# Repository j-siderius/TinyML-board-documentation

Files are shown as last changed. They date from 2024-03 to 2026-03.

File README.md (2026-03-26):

# TinyML Board Documentation

Board version: 2.1

The TinyML board is a development board specifically tailored to the exploration of TinyML concepts and to test possible applications of TinyML in an easy way. It features a powerfull microcontroller as well as a suite of sensors to sense the environment. Combined with a special TensorFlow Lite Micro library, it is easy to use this devide and start deploying machine learning models to the Edge.

<div align="center">
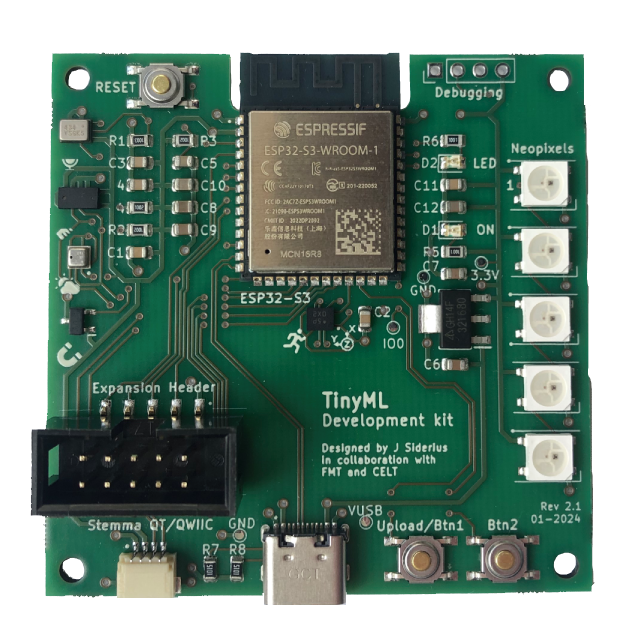
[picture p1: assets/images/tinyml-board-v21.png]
TinyML board
    
</div>

## Contents
- [Quick start](#quick-start)
- [Hardware](#hardware)
  - [Sensors](#sensors)
  - [Processor](#processor)
  - [Input/Output](#inputoutput)
  - [Expansion headers](#expansion-headers)
- [Software](#software)
  - [Arduino](#arduino-ide)
  - [IDE configuration](#ide-configuration)
  - [Serial Port Setup](#serial-port-setup)
  - [Libraries](#arduino-libraries)
  - [TensorFlow Lite Micro library](#tensorflow-lite-micro-library)
  - [Uploading code](#uploading-code)
- [Code examples](#code-examples)
  - [Sensor examples](#sensor-examples)
  - [I/O examples](#io-examples)
  - [TensorFlow Lite Micro examples](#tensorflow-lite-micro-examples)
  - [Board tests](#board-tests)
- [Frequently Encountered Issues](#frequently-encountered-issues)
- [License](#license-and-contact)

## Quick start

 1. Install the ESP32 board support into Arduino IDE by adding the Espressif repository to the Board Manager and then downloading the ESP32 boards - [Espressif Arduino ESP32 installation](https://docs.espressif.com/projects/arduino-esp32/en/latest/installing.html#installing-using-arduino-ide).
 2. Install libraries for the sensors ([Sparkfun BME280](https://github.com/sparkfun/SparkFun_BME280_Arduino_Library), [Sparkfun BMI270](https://github.com/sparkfun/SparkFun_BMI270_Arduino_Library), [Pololu VL53L0X](https://github.com/pololu/vl53l0x-arduino) and [FastLED](https://github.com/FastLED/FastLED)) using the Library Manager and TensorFlow Lite Micro ([TFLiteMicro_ArduinoESP32S3](https://github.com/j-siderius/TFLiteMicro_ArduinoESP32S3)) from the GitHub page.
 3. Choose an [example project](#code-examples) for the TinyML board and load the code into Arduino IDE.
 4. Configure the TinyML board using the [Arduino IDE settings](#ide-configuration). Press and hold the `Upload/Btn1` button, then press the `RESET` button. Release all buttons and click `Upload`, then wait for the code to upload.
 5. Check the Serial Monitor or Serial Plotter in Arduino IDE to see the output from the model.

More detailed instructions can be found in the corresponding sections below.

[🔼 Back to the top](#tinyml-board-documentation)

## Hardware

The TinyML board contains several sensors and a powerfull processor to get up and running with TinyML quickly. In the following sections, a general overview as well as technical details on all hardware can be found.

<div align="center">
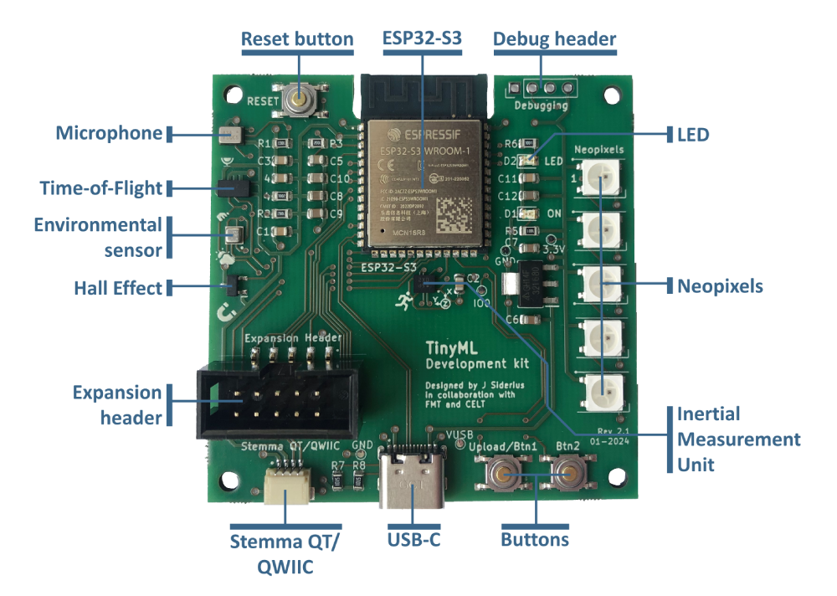
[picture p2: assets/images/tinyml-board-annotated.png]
TinyML board annotated
    
</div>

### Sensors

The TinyML board contains five different sensors that can be used for gathering data. To see how to use the sensors, look at the [Code Examples](#code-examples). For detailed information about the circuit board, refer to the [Circuit board documentation](/pcb/README.md).

- **Microphone (I2S)** [_ICS-43434_](assets/datasheets/ics43434.pdf) - This sensor measures the amplitude and pitch of sound.
- **Time-of-Flight range sensor** [_VL53L0X_](assets/datasheets/vl53l0x.pdf) - This sensor measures short-range distance.
- **Environmental sensor** [_BME280_](assets/datasheets/bme280.pdf) - This sensor measures temperature, relative humidity and atmospheric pressure.
- **Hall effect magnet sensor** [_AH49E_](assets/datasheets/ah49e.pdf) - This sensor measures the magnetic field around its axis.
- **Inertial Measurement Unit (IMU)** [_BMI270_](assets/datasheets/bmi270.pdf) - This sensor measures both the angular motion using a gyroscope, as well as the acceleration using an accelerometer.

### Processor

The TinyML board is fitted with an ESP32-S3 SoC. The processor features a fast 240MHz, dual-core processor, large 16MB storage and 8MB RAM. 
Additionally, it has Bluetooth 5 and WiFi capabilities, making it easy to connect the TinyML board to the internet, for example to share sensor data.
More information about the onboard chip can be found in the datasheet: [ESP-S3-WROOM1-N16R8](assets/datasheets/esp32s3wroom1.pdf).

### Input/Output

Besides sensors, the TinyML board also contains multiple Inputs and Outputs (I/O). To see how to use the I/O, look at the [Code Examples](#code-examples).

- **Buttons** - Two buttons are accessible to the user (`Upload/Btn1` and `Btn2`), which can be user-configured. Both buttons need to be pulled high by the processor (see the [Code Examples](#code-examples)).
  The last button (`RESET`) is used if the board needs to be programmed or debugged, e.g. if the TinyML board or the application need to be restarted.
- **Output LED** - The red LED can be used as simple output, e.g. for showing if a sensor functions properly. The output LED is marked `LED` on the TinyML board.
- **Neopixels** - The Neopixel LEDs can be addressed individually to display RGB colors. They can output application information, give users feedback and more. The Neopixels are marked `Neopixels` on the TinyML board.

- **USB-C connector** - This connector is primarily used for programming and serial communication with the TinyML board. It is also the primary power input for the board. To program the board, a USB-C _Data_ cable is needed.
- **Stemma QT / QWIIC** - This connector enables users to connect extra sensors, making the TinyML board suitable for even more advanced projects.
  The connector uses the popular [Adafruit Stemma QT](https://www.adafruit.com/category/620) and [SparkFun QWIIC](https://www.sparkfun.com/categories/399) standards, opening up the possibilty for many extra sensors.
  Using a Stemma QT expansion board, users can connect even more sensors in series. For the pinout, refer to the [Expansion headers](#expansion-headers) section. This connector if marked `Stemma QT/QWIIC` on the TinyML board.
- **Expansion header** - This connector can be used to connect extra peripherals, sensors, actuators and more to adapt the TinyML board to different projects. This connector is marked `Expansion Header` on the TinyML board.
  The connector features power, digital and analog connections, as well as support for the SPI high-speed databus. In combination with the ESP32S3's built in GPIO multiplexer, the connector gives the freedom to connect many different things to the TinyML board.
  For the pinout, refer to the [Expansion headers](#expansion-headers) section.

- **Miscellaneous** - The TinyML board also contains some other, miscellaneous component.
  These components are used to show power (green LED, marked `ON` on the TinyML board), convert voltage, debug the TinyML board (header, marked `Debugging` on the TinyML board) and some other passive components. Additionally, the board features some test-points (2x GND, VUSB, 3.3V and IO0) which can be used to verify the functionality of some components.

### Expansion headers

Below a systematic overview of all expansion headers present on the TinyML board is shown. The Expansion header features four analog GPIO pins (A1 - A4 in the top row), four digital GPIO pins (D1 - D4 in the bottom row), as well as 3.3V power and ground (GND). The digital GPIO pins also expose the SPI data bus of the ESP32S3 microcontroller as follows:

| GPIO pin | Description |
| --- | --- |
| D1 / GPIO14 | SPI CS |
| D2 / GPIO11 | SPI MOSI |
| D3 / GPIO12 | SPI SCK |
| D4 / GPIO13 | SPI MISO |

The TinyML board can technically be powered through the Expansion Header, but the power should be stable and noise-free **3.3V** only. If the external power is fluctuating, the microcontroller could be damaged. If it is absolutely nescessary to provide variable external power from another source than USB-C (e.g. from a battery), it is possible to utilise the testpoints GND and VUSB close to the USB-C connector on the board. The VUSB testpoint routes the power through the on-board voltage regulator first, which produces clean 3.3V.

<div align="center">
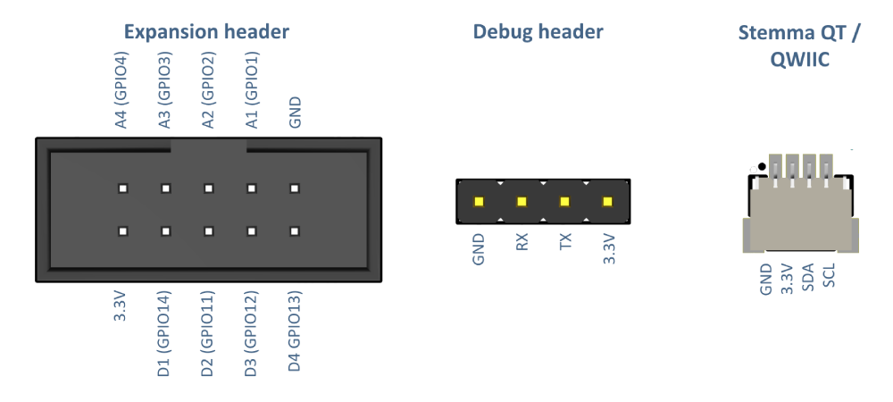
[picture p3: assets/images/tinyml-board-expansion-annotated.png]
TinyML board headers annotated
    
</div></div>

[🔼 Back to the top](#tinyml-board-documentation)

## Software

In order to use the TinyML board, it needs to be correctly setup. The TinyML board requires no hardware setup, but it does require some software setup. In order to start using it, connect a USB-C _Data_ cable to the board and plug it into a free USB port on the system. Below sections detail the setup of the Arduino IDE, installation of sensor libraries and finally the TensorFlow Lite Micro setup.

### Arduino IDE

The TinyML board can be programmed using the [Arduino IDE](https://www.arduino.cc/en/software), both the new 2.x and Legacy >1.8 versions.
Please make sure that the Arduino IDE is installed on the system before continuing.

In order to program the TinyML board, the [ESP32](#processor) platform need to be installed. To do this, follow the steps below:

1. Open the Arduino IDE and navigate to the `Preferences` (_Windows_: File > Preferences, _Mac_: Arduino > Preferences), as shown in the left image below.
2. In the field `Additional boards manager URLs:` enter the following link (If there are already other URLs in this field,
   open the full list by clicking the folder icon to the right of the URL):
   ```
   https://espressif.github.io/arduino-esp32/package_esp32_index.json
   ```   
3. Press `Ok` to close the `Preferences`.
4. Open the `Boards Manager` by going to Tools > Boards > Boards Manager.
5. Search for **ESP32** and install the platform by Espressif Systems.
6. Restart the Arduino IDE.

<div align="center">
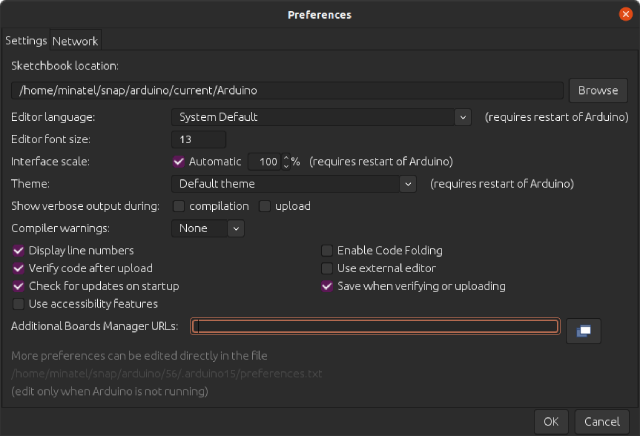
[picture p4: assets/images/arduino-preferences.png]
Arduino Preferences menu
    
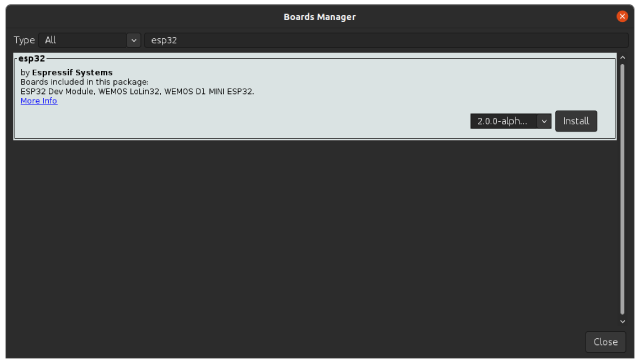
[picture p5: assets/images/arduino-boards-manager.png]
Arduino Boards Manager
    
</div>

For more advanced installations, for example in Platform IO, follow this [advanced installation guide](https://docs.espressif.com/projects/arduino-esp32/en/latest/installing.html).

### IDE configuration

In order to use all functions that the ESP32S3 processor has, Arduino IDE must be properly configured when programming the TinyML board. Below are the most important settings, these need to be configured in the `Tools menu` (_Windows_ + _Mac_: Tools) by clicking on the setting and choosing the correct option:

- **Board** - *ESP32S3 Dev Module*: This sets the correct processor and board configuration for the TinyML board. To select the ESP32 Dev Module, first select the *esp* platform.
- **Port** - *port here*: Enter the serial port of the TinyML board here. Refer to the guide [Serial Port](#serial-port-setup) to find this port.
- **USB CDC On Boot** - *Enabled*: This setting enables the onboard USB-C port to be used for serial communication.
- **Flash mode** - *DIO 80MHz*: This setting configures the correct mode for writing to the flash of the ESP32S3.
- **Flash Size** - *16MB (128Mb)*: This setting uses the full storage of the ESP32S3, enabling space for larger projects and more code.
- **PSRAM** - *OPI PSRAM*: This setting enables the fast built-in RAM of the ESP32S3.

<div align="center">
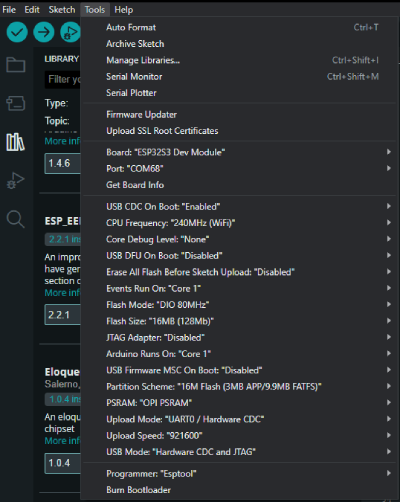
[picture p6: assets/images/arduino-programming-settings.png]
Arduino Board settings
    
</div>

### Serial Port setup

No drivers are required for the TinyML board. However, sometimes, it is nescessary to know on which serial port the TinyML board is connected. To find this out, perform the following steps:

_Arduino IDE_
1. Open the `Port overview menu` (_Windows_ + _Mac_: Tools > Port) and observe which ports are in the list. 
2. Close the list.
3. Plug in the TinyML board and open the `Port overview menu`, observe which port was added to the list > this is the TinyML board port.

If the above method does not work, an OS-specific check can be done using the instructions below:

_Windows_
1. Open `Device Manager` by going to Start and searching for the program. (Alternatively, press the <kbd>Windows Key</kbd> key and search for Device Manager)
2. Open the `Ports (COM & LPT)` section.
3. Plug in the TinyML board and observe which COM port was added to this list > this is the TinyML board port.

_Mac_
1. Open the `Terminal` application by going to Applications > Utilities. (Alternatively, press the <kbd>CMD Key + Spacebar</kbd> keys and search for Terminal)
2. Enter the following command `ls /dev/tty*` and press <kbd>Enter</kbd>.
3. Plug in the TinyML board and repeat step 2, observe which port was added to the list > this is the TinyML board port.

### Arduino libraries

In order to use the sensors on the TinyML board, some Arduino libraries are needed. The recommended libraries are listed below, although other libraries might work as well.

The libraries can be installed into Arduino IDE through the Library Manager (Sketch > Include Library > Manage Libraries). The versions are included here for documentation purpose, the newest version of each library should work fine.

- [Sparkfun BME280](https://github.com/sparkfun/SparkFun_BME280_Arduino_Library) (2.0.10 or later)
- [SparkFun BMI270](https://github.com/sparkfun/SparkFun_BMI270_Arduino_Library) (1.0.3 or later)
- [Pololu VL53L0X](https://github.com/pololu/vl53l0x-arduino) (1.3.1 or later)
- [FastLED](https://github.com/FastLED/FastLED) (3.9.13 or later)

The onboard [Microphone](#sensors) uses the built-in I2S library from Espressif, so there is no library to install to use the microphone. More information can be found in the [I2S Peripherals documentation](https://docs.espressif.com/projects/esp-idf/en/v3.3/api-reference/peripherals/i2s.html). 

### TensorFlow Lite Micro library

In order to run TensorFlow Lite Micro models on the TinyML board, the [TFLiteMicro_ArduinoESP32S3](https://github.com/j-siderius/TFLiteMicro_ArduinoESP32S3) library needs to be installed. Download the libary from its homepage and install it in the Arduino IDE by using the Library Manager (Sketch > Include Library > Add .ZIP Library). More information on installing ZIP-libraries on Arduino can be found on the [Arduino website](https://docs.arduino.cc/software/ide-v1/tutorials/installing-libraries/#importing-a-zip-library).

> [!IMPORTANT]
> Be aware that not all TensorFlow (Keras) layers are supported by TensorFlow Lite Micro. Some layers may also have a different name in TensorFlow Lite Micro, compared to their name in TensorFlow (Keras), for example the `LSTM` layer is called `UnidirectionalSequenceLSTM`.
> 
> <details><summary>Supported layers</summary>
> Abs
> Add
> AddN
> ArgMax
> ArgMin
> AssignVariable
> AveragePool2D
> BatchMatMul
> BatchToSpaceNd
> BroadcastArgs
> BroadcastTo
> CallOnce
> Cast
> Ceil
> CircularBuffer
> Concatenation
> Conv2D
> Cos
> CumSum
> Delay
> DepthToSpace
> DepthwiseConv2D
> Dequantize
> DetectionPostprocess
> Div
> EmbeddingLookup
> Energy
> Elu
> Equal
> EthosU
> Exp
> ExpandDims
> FftAutoScale
> Fill
> FilterBank
> FilterBankLog
> FilterBankSquareRoot
> FilterBankSpectralSubtraction
> Floor
> FloorDiv
> FloorMod
> Framer
> FullyConnected
> Gather
> GatherNd
> Greater
> GreaterEqual
> HardSwish
> If
> Irfft
> L2Normalization
> L2Pool2D
> LeakyRelu
> Less
> LessEqual
> Log
> LogicalAnd
> LogicalNot
> LogicalOr
> Logistic
> LogSoftmax
> Maximum
> MaxPool2D
> MirrorPad
> Mean
> Minimum
> Mul
> Neg
> NotEqual
> OverlapAdd
> Pack
> Pad
> PadV2
> PCAN
> Prelu
> Quantize
> ReadVariable
> ReduceMax
> Relu
> Relu6
> Reshape
> ResizeBilinear
> ResizeNearestNeighbor
> Rfft
> Round
> Rsqrt
> SelectV2
> Shape
> Sin
> Slice
> Softmax
> SpaceToBatchNd
> SpaceToDepth
> Split
> SplitV
> Squeeze
> Sqrt
> Square
> SquaredDifference
> StridedSlice
> Stacker
> Sub
> Sum
> Svdf
> Tanh
> TransposeConv
> Transpose
> Unpack
> UnidirectionalSequenceLSTM
> VarHandle
> While
> Window
> ZerosLike
> </details>

<!-- Not all normal TensorFlow Ops (layers) are supported by TensorFlow Lite Micro. In order to see what operations the TensorFlow model uses, you can upload your saved model to [Netron](https://netron.app/) and examine it. The supported operations in this version of TensorFlow Lite Micro can be found in the [Arduino-TensorFlowLite-ESP32 README](/arduino-tensorflowlite-esp32/README.md#supported-ops). -->

<!-- > [!IMPORTANT]
> The TensorFlow Lite Micro ESP32 library included in this repository works with the TensorFlow Lite Micro release from Feb 2023.
> With much manual modifications, the library can be updated, however there is no compatibility guarantee as much of the TensorFlow Lite Micro codebase has changed without proper notice and documentation. -->

### Uploading code

To upload a program to the TinyML board, follow the steps below:

1. Connect the TinyML board to the system using a USB-C _Data_ cable.
2. Ensure that the IDE settings are setup as described in the [Arduino IDE](#arduino-ide) and [IDE configuration](#ide-configuration) sections.
3. Select the correct serial port for the TinyML board, as described in the [Serial Port setup](#serial-port-setup) section.
4. Optionally, on older versions of the Arduino IDE: Press and hold the `Upload/Btn1` button, then press the `RESET` button. This puts the ESP32S3 into *Upload*\* mode. Release all buttons after a couple of seconds.
5. Click `Upload`, then wait for the code to upload.

\* Technically, this mode is called *Download*, since the code is downloaded to the microcontroller, but for ambiguities sake, it is called *Upload* here.

[🔼 Back to the top](#tinyml-board-documentation)

## Code examples

Example code for all described functions of the TinyML board can be found below. They are divided into sensors, I/O and TensorFlow Lite Micro examples.

The TinyML board usually comes pre-programmed with a Board Test firmware. This program tests all functionality of the TinyML board. To start the test, just connect the TinyML board to the system and open the Serial Monitor in Arduino IDE (_Windows_ + _Mac_: either through GUI button or Tools > Serial Monitor).

Additional (advanced) examples can be found in the [ESP32 Arduino library documentation](https://docs.espressif.com/projects/arduino-esp32/en/latest/libraries.html).

### Sensor examples

<!---
- Microphone [![Open In Github](assets/images/github-badge.svg)](assets/example-code/tinyml-board-microphone-example/)
--->
- Microphone => Currently there is a software bug that prevents the microphone from being used
- Time-of-Flight sensor Open In Github
- Environmental sensor Open In Github
- Hall-effect magnetic sensor Open In Github
- Inertial Measurement Unit (IMU) Open In Github

### I/O examples

- Buttons Open In Github
- LED Open In Github
- Neopixels Open In Github
- Expansion header Open In Github

### TensorFlow Lite Micro examples

Please find all TensorFlow Lite Micro examples in the TFLiteMicro_ArduinoESP32S3 library repository: [TFLiteMicro_ArduinoESP32S3 examples](https://github.com/j-siderius/TFLiteMicro_ArduinoESP32S3/#examples).

### Board tests

- TinyML Board Test Open In Github

[🔼 Back to the top](#tinyml-board-documentation)

## Frequently Encountered Issues

#### The TinyML board serial port does not appear in Arduino IDE when connected

Make sure to use a USC-C _Data_ cable, since the TinyML board can only communicate with the system when it has both power and data connections. Some cheaper cables only provide power wires.

#### The ESP32S3 Dev Module cannot be selected as board in Arduino IDE

Make sure to have the ESP32 platform installed in the Arduino IDE. Refer to the [Software - Arduino IDE](#arduino-ide) section for a guide how to do this.

#### It is not possible to upload code to the TinyML board

When getting a `Failed to connect to ESP32-S3` error in Arduino IDE, it is possible that the TinyML board was not in Upload mode. To get the TinyML board in this mode, follow the [Uploading code](#uploading-code) section. 
<!-- Alternatively, update the Arduino IDE to the latest version (2.3.4 as of February 2025) and update the ESP32 platform to the latest version (3.1.1 as of February 2025); the upload process will now be automated. -->

#### The serial upload fails

When getting an `A serial exception error occurred` error in Arduino IDE, there are multiple possibilities:
- If the writing and verification of bytes was successful, check if the Arduino code works as expected, usually the code was uploaded correctly, but the programmer fails after the restart.
- If the writing was not successful, follow the troubleshooting steps on the [Espressif Esptool website](https://docs.espressif.com/projects/esptool/en/latest/esp32/troubleshooting.html).

#### Missing library in Arduino IDE

When getting an `Fatal error: <library_name>.h: No such file or directory` error in Arduino IDE, it is likely that the software library required for the code is not installed. Follow the [Arduino libraries](#arduino-libraries) section to install all required libraries.

#### Arduino sketch too large

When getting an `Sketch too big` error, the storage of the TinyML board was exceeded. First, make sure that Arduino utilises the whole onboard Flash memory by checking the [IDE configuration](#ide-configuration). If the code is still too large, decrease the Arduino sketch size:
- Reduce the size of bytearrays included in the code (e.g. storing images).
- Reduce the size of the TensorFlow Lite Micro model by tweaking the TensorFlow model (e.g. by condensing or removing layers).
- Reduce the amount of libraries that are included in the Arduino sketch, especially if they are unused.

#### Code contains unsupported operators

When getting an `Encountered ERROR: TFLite operator with code <code_here> is unsupported` error, an operator or layer that is not supported by TFLite Micro was present in the code. When making the TensorFlow model that will be utilised on the TinyML board, make sure to only use the supported layers. These are described in the [TensorFlow Lite Micro library](#tensorflow-lite-micro-library) section.

#### The TinyML board does not print any output to the Serial Monitor

If no output is found on the Serial Monitor in Arduino IDE, the USB CDC option is probably misconfigured. Refer to the [IDE configuration](#ide-configuration) section to setup the *USB CDC on Boot* option correctly.

If the Serial Monitor in Arduino IDE only displays garbage output, make sure that the correct baudrate is set up. The default baudrate for the [Code examples](#code-examples) is `115200`. Refer to the [Arduino Serial Monitor](https://docs.arduino.cc/software/ide-v2/tutorials/ide-v2-serial-monitor/#using-the-serial-monitor-tool) guide to configure the Serial Monitor.

#### TinyML board keeps crashing after uploading code

When getting a looping error `rst:0x10  (RTCWDT_RTC_RESET),boot:0x13 (SPI_FAST_FLASH_BOOT)`, `rst:0x3 (SW_RESET),boot:0x13 (SPI_FAST_FLASH_BOOT)` or `rst:0x1  (POWON),boot:0xd (SPI_FAST_FLASH_BOOT)`, this means that the TinyML board is stuck in a boot loop. Usually this problem is caused by a fault, overload or memory corruption problem in the code, so check the whole Arduino code for errors.

#### Onboard sensors are not initialising or giving error

Make sure to use the correct I2C addresses for all of the onboard sensors. The [Sensor code examples](#sensor-examples) for each sensor contain the correct I2C address and initialisation code. The addresses are also listed below:

- **BMI270** - `0x69`
- **BME280** - `0x76`
- **VL53L0X** - `0x29`

#### Onboard buttons do not recognised presses

Make sure to pullup both onboard buttons (`Upload/Btn1` and `Btn2`), like shown in the [I/O code examples](#io-examples). Both buttons should be initialised using the `INPUT_PULLUP` option in Arduino. An example code for a button could be:

```cpp
#define pin_button1 0
void setup() {
  pinMode(pin_button1, INPUT_PULLUP);
}
```

#### TinyML board crashed randomly on brownout

When getting a `Brownout detector was triggered` error message, the TinyML board temporarily received too little power to run the microcontroller (called a brownout). The brownout occurs when the microcontroller and pheripherals draw much power, for example during sensor readings or large calculations. This problem is usually caused by either a bad USB-C _Data_ cable (with thin wires) or a bad power supply (e.g. the computer USB port not providing enough current). To solve this, try another USB-C _Data_ cable and / or power supply.

[🔼 Back to the top](#tinyml-board-documentation)

## License

$\color{red}{\textsf{TODO:}}$ Add license information here

<br>

[🔼 Back to the top](#tinyml-board-documentation)

&copy; Jannick Siderius

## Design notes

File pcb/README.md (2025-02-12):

# Circuit Board documentation

This folder contains the circuit board files and schematics.

The PCB was setup and designed in [KiCad 7](https://www.kicad.org/).

Boards were manufactured and assembled by [Eurocircuits](https://www.eurocircuits.com/) in Belgium.

## Pin layout

The pin layout of the ESP32S3 is as follows:

| Pin | Connection |
|---|---|
| IO0 | Button 1 / Upload |
| IO1 | Analog 1 |
| IO2 | Analog 2 |
| IO3 | Analog 3 |
| IO4 | Analog 4 |
| IO5 | I2S SD |
| IO6 | I2S WS |
| IO7 | I2S SCK|
| IO8 | I2C SDA |
| IO9 | I2C SCL |
| IO10 | Hall Effect sensor |
| IO11 | SPI MOSI / Digital 2 |
| IO12 | SPI SCK / Digital 3 |
| IO13 | SPI MISO / Digital 4 |
| IO14 | SPI CS / Digital 1 |
| IO17 | LED |
| IO18 | Neopixels |
| IO19 | USB D- |
| IO20 | USB D+ |
| IO21 | IMU wake interrupt |
| IO47 | Button 2 |
| TXD0 | TX |
| RXD0 | RX |

## I2C addresses

The sensors are connected with the following I2C addresses:

- **BMI270** - 0x69
- **BME280** - 0x76
- **VL53L0X** - 0x29

<br>

&copy; Jannick Siderius

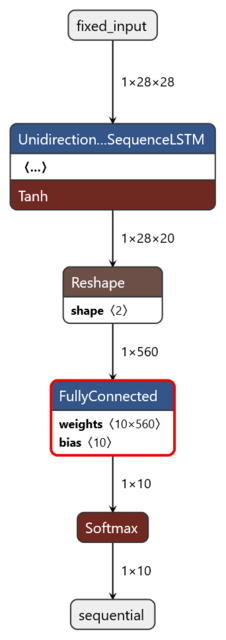
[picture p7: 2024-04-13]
assets/images/lstm_model_tflite.png

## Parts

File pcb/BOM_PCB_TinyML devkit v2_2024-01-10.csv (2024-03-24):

ID | Name | Footprint | Quantity | Manufacturer Part | Manufacturer | Supplier | Supplier Part
1 | 4.7u | C0805 | 2
2 | 1u | C0805 | 1
3 | 10u | C0805 | 4
4 | 0.1u | C0805 | 5
5 | SBH11-NBPC-D05-SM-BK | SBH11-NBPC-D05-SM-BK | 1 | SBH11-NBPC-D05-SM-BK | Sullins | Digi-Key | S9185-ND
6 | LED-0805_G | LED0805_GREEN | 1 | NCD0805G1 | 国星光电 |  | C84260
7 | LED-0805_R | LED0805_RED | 1 | 17-21SURC/S530-A3/TR8 | EVERLIGHT(台湾亿光) |  | C72037
8 | 1k | R0805 | 2
9 | 5.1k | R0805 | 2
10 | 10k | R0805 | 3
11 | 100k | R0805 | 1
12 | PTS526SK15SMTR2LFS | SW-SMD_4P-L5.2-W5.2-P3.70-LS6.4 | 3 | PTS526SK15SMTR2LFS | C&K | LCSC | C2689521
13 | ESP32-S3-WROOM-1(N16R8) | WIRELM-SMD_ESP32-S3-WROOM-1 | 1 | ESP32-S3-WROOM-1-N16R8 | ESPRESSIF(乐鑫) | LCSC | C2913202
14 | AP2114HA-3.3TRG1 | SOT-223-3_L6.5-W3.4-P2.30-LS7.0-BR | 1 | AP2114HA-3.3TRG1 | DIODES(美台) | LCSC | C460314
15 | BME280 | LGA-8_BME280_BL | 1 | BME280 | Bosch(博世) | LCSC | C92489
16 | BMI270 | LGA-14_L3.0-W2.5-P0.50-BR | 1 | BMI270 | Bosch(博世) | LCSC | C2836813
17 | VL53L0CXV0DH/1 | OPTO-SMD_12P_VL53L0CXV0DH-1 | 1 | VL53L0CXV0DH/1 | ST(意法半导体) | LCSC | C91199
18 | ICS-43434 | MIC-SMD_6P-L3.5-W2.7-P0.90-BL | 1 | ICS-43434 | null | LCSC | C9900000518
19 | AH49FNTR-G1 | SC-59-3_L2.9-W1.6-P0.95-LS2.9-BR | 1 | AH49FNTR-G1 | DIODES(美台) | LCSC | C176936
20 | 5050WS2812B | LED-SMD_5050WS2812B | 5 | 5050WS2812B | null | LCSC | C2874876
21 | SM04B-SRSS-TB | CONN-SMD_SM04B-SRSS-TB | 1 | SM04B-SRSS-TB | null | LCSC | C9900000999
22 | USB4105-GF-A | TYPE-C-SMD_SBC-160S1A-20-S412 | 1 | USB4105-GF-A | null | LCSC | C3020560

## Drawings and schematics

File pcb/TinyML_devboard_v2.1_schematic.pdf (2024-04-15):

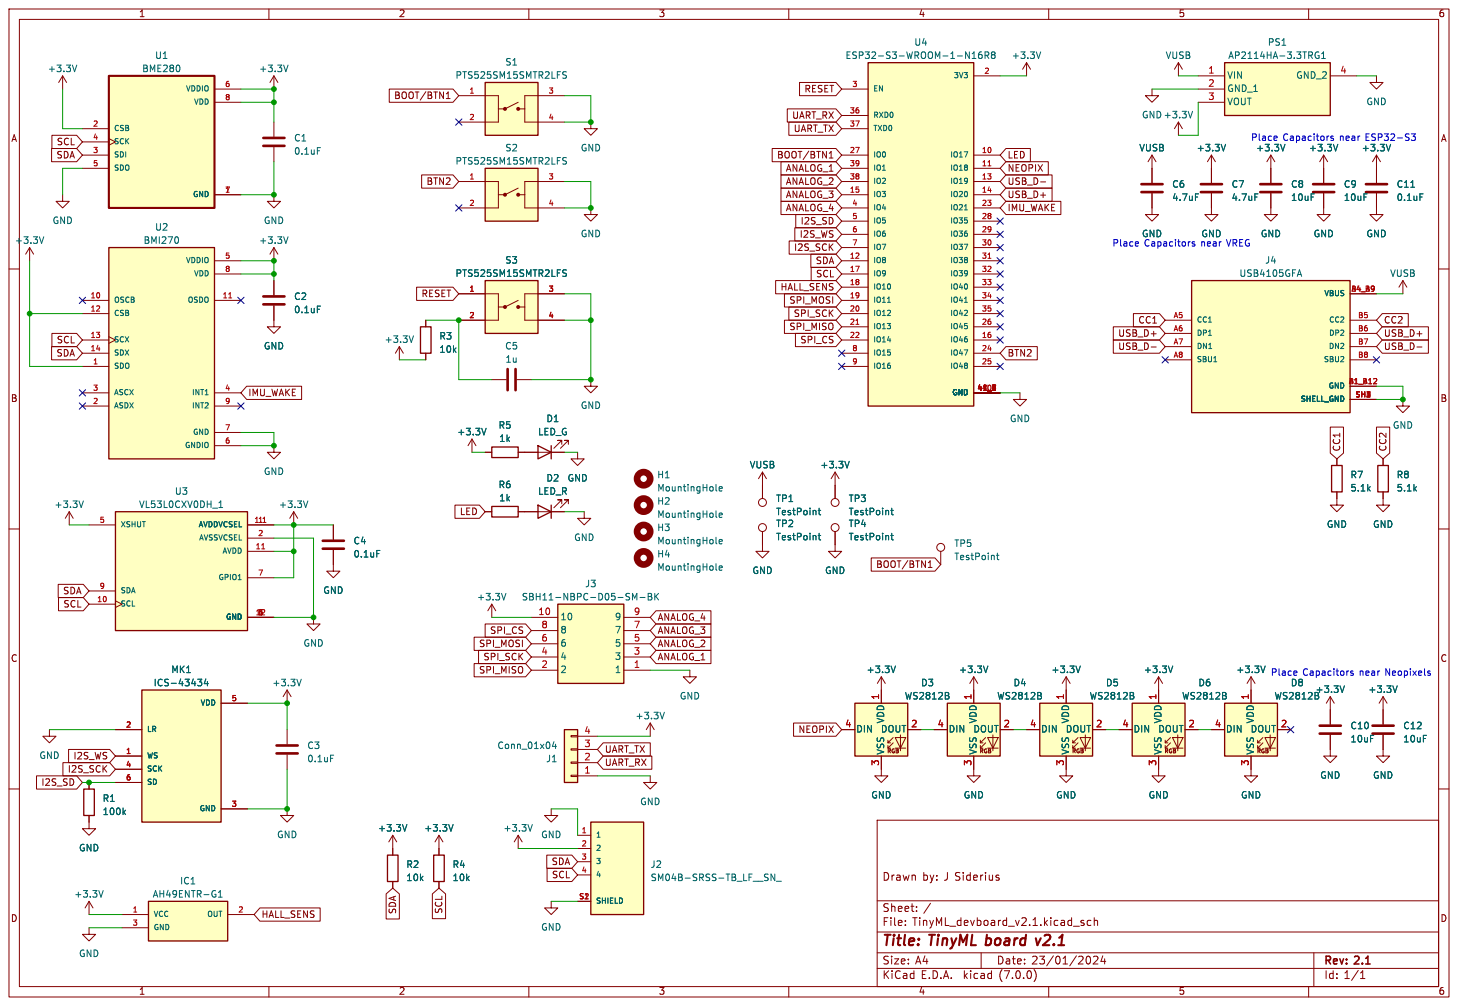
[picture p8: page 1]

Id: 1/1 Title: TinyML board v2.1

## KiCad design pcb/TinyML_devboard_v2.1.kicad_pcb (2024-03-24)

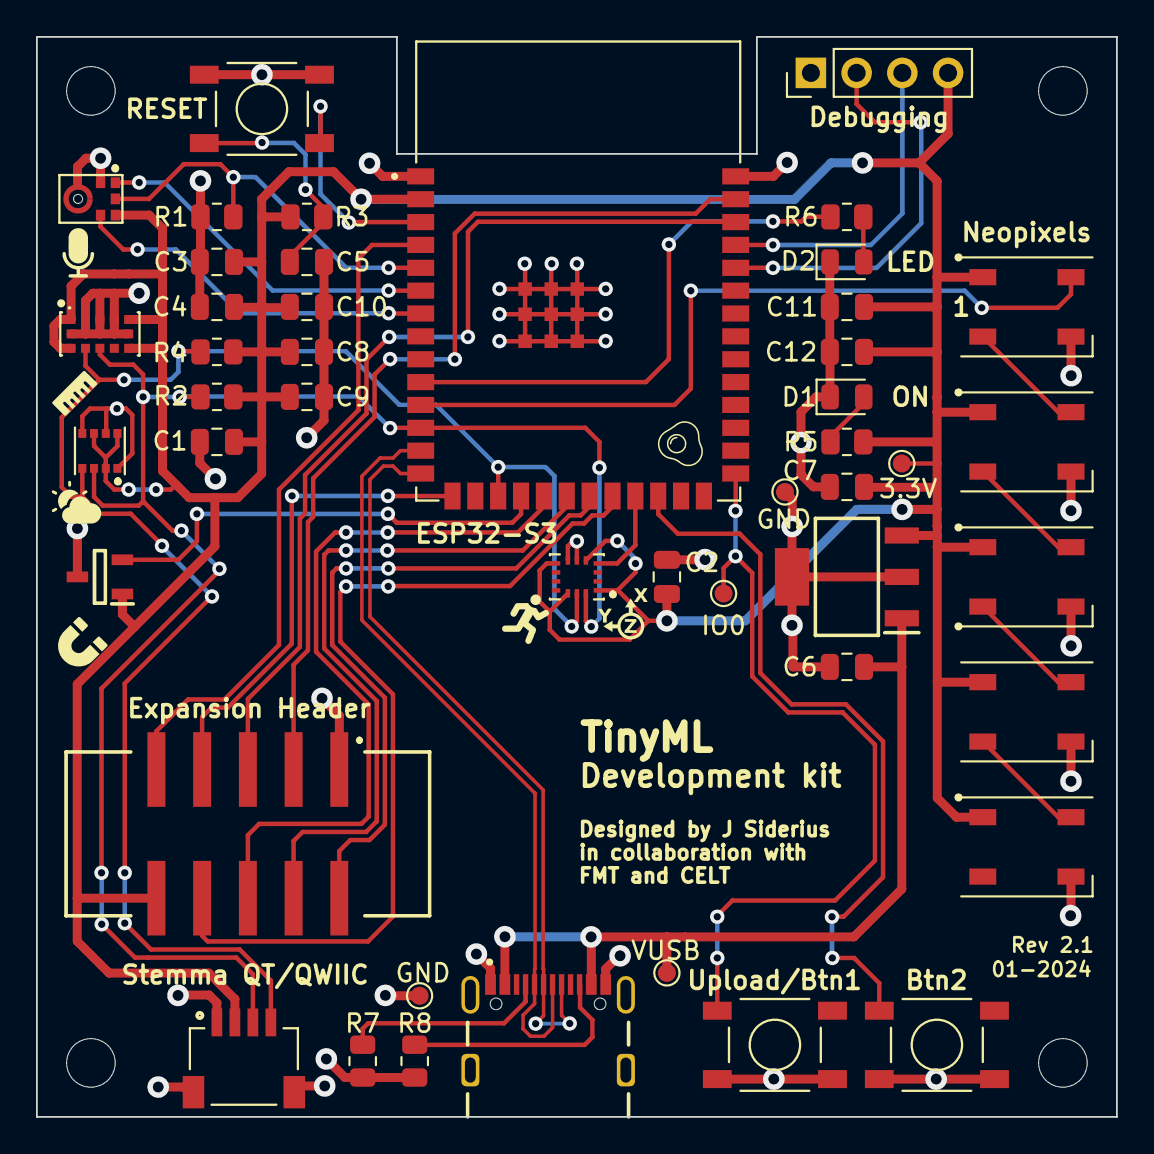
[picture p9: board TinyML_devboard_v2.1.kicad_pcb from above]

Board: 2 copper layers, 60.0 x 60.0 mm, 50 parts (0 on the bottom side), 36 nets.

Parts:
3.3V: TestPoint; TestPoint_Pad_D1.0mm
C1, C2, C3, C4, C11: 0.1u; C_0805_2012Metric
C5: 1u; C_0805_2012Metric
C6, C7: 4.7u; C_0805_2012Metric
C8, C9, C10, C12: 10u; C_0805_2012Metric
D1: LED_G; LED_0805_2012Metric
D2: LED_R; LED_0805_2012Metric
D3, D4, D5, D6, D8: WS2812B; LED_WS2812B_PLCC4_5.0x5.0mm_P3.2mm
GND: TestPoint; TestPoint_Pad_D1.0mm
GND#2: TestPoint; TestPoint_Pad_D1.0mm
H1, H2, H3, H4: MountingHole; MountingHole_2.7mm_M2.5
IC1: AH49ENTR-G1; SOT95P280X145-3N
IO0: TestPoint; TestPoint_Pad_D1.0mm
J1: Conn_01x04; PinHeader_1x04_P2.54mm_Vertical
J2: SM04B-SRSS-TB_LF__SN_; JST_SM04B-SRSS-TB_LF__SN_
J3: SBH11-NBPC-D05-SM-BK; SBH11NBPCD05SMBK
J4: USB4105GFA; GCT_USB4105GFA
MK1: ICS-43434; MIC_ICS-43434
PS1: AP2114HA-3.3TRG1; SOT230P700X180-4N
R1: 100k; R_0805_2012Metric
R2, R3, R4: 10k; R_0805_2012Metric
R5, R6: 1k; R_0805_2012Metric
R7, R8: 5.1k; R_0805_2012Metric
S1, S2, S3: PTS525SM15SMTR2LFS; SW_PTS525SM15SMTR2LFS
U1: BME280; PSON65P250X250X100-8N
U2: BMI270; XDCR_BMI270
U3: VL53L0CXV0DH_1; XDCR_VL53L0CXV0DH_1
U4: ESP32-S3-WROOM-1-N16R8; XCVR_ESP32-S3-WROOM-1-N16R8
VUSB: TestPoint; TestPoint_Pad_D1.0mm

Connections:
+3.3V: 3.3V.1, C1.1, C2.1, C3.1, C4.1, C7.1, C8.1, C9.1, C10.1, C11.1, C12.1, D3.1 (VDD), D4.1 (VDD), D5.1 (VDD), D6.1 (VDD), D8.1 (VDD), IC1.1 (VCC), J1.4, J2.2, J3.10, MK1.5 (VDD), PS1.3 (VOUT), R2.1, R3.1, R4.1, R5.2, U1.2 (CSB), U1.6 (VDDIO), U1.8 (VDD), U2.1 (SDO), U2.5 (VDDIO), U2.8 (VDD), U2.12 (CSB), U3.1 (AVDDVCSEL), U3.1.1 (AVDDVCSEL), U3.5 (XSHUT), U3.7 (GPIO1), U3.11 (AVDD), U4.2 (3V3)
ANALOG_1: J3.3, U4.39 (IO1)
ANALOG_2: J3.5, U4.38 (IO2)
ANALOG_3: J3.7, U4.15 (IO3)
ANALOG_4: J3.9, U4.4 (IO4)
BOOT/BTN1: IO0.1, S1.1, U4.27 (IO0)
BTN2: S2.1, U4.24 (IO47)
CC1: J4.A5 (CC1), R7.1
CC2: J4.B5 (CC2), R8.1
GND: C1.2, C2.2, C3.2, C4.2, C5.2, C6.2, C7.2, C8.2, C9.2, C10.2, C11.2, C12.2, D1.1 (K), D2.1 (K), D3.3 (VSS), D4.3 (VSS), D5.3 (VSS), D6.3 (VSS), D8.3 (VSS), GND.1, GND#2.1, IC1.3 (GND), J1.1, J2.1, J2.S1 (SHIELD), J2.S2 (SHIELD), J3.1, J4.A1_B12 (GND), J4.B1_A12 (GND), J4.SH1 (SHELL_GND), J4.SH2 (SHELL_GND), J4.SH3 (SHELL_GND), J4.SH4 (SHELL_GND), MK1.2 (LR), MK1.3 (GND), PS1.2 (GND_1), PS1.4 (GND_2), R1.2, R7.2, R8.2, S1.3, S1.4, S2.3, S2.4, S3.3, S3.4, U1.1 (GND), U1.5 (SDO), U1.7 (GND), U2.6 (GNDIO), U2.7 (GND), U3.2 (AVSSVCSEL), U3.3 (GND), U3.4 (GND), U3.6 (GND), U3.12 (GND), U4.1 (GND), U4.40 (GND), U4.41_7 (GND)
HALL_SENS: IC1.2 (OUT), U4.18 (IO10)
I2S_SCK: MK1.4 (SCK), U4.7 (IO7)
I2S_SD: MK1.6 (SD), R1.1, U4.5 (IO5)
I2S_WS: MK1.1 (WS), U4.6 (IO6)
IMU_WAKE: U2.4 (INT1), U4.23 (IO21)
LED: R6.2, U4.10 (IO17)
NEOPIX: D3.4 (DIN), U4.11 (IO18)
unnamed: C5.1, R3.2, S3.2
unnamed: D1.2 (A), R5.1
unnamed: D2.2 (A), R6.1
unnamed: D3.2 (DOUT), D4.4 (DIN)
unnamed: D4.2 (DOUT), D5.4 (DIN)
unnamed: D5.2 (DOUT), D6.4 (DIN)
unnamed: D6.2 (DOUT), D8.4 (DIN)
RESET: S3.1, U4.3 (EN)
SCL: J2.4, R4.2, U1.4 (SCK), U2.13 (SCX), U3.10 (SCL), U4.17 (IO9)
SDA: J2.3, R2.2, U1.3 (SDI), U2.14 (SDX), U3.9 (SDA), U4.12 (IO8)
SPI_CS: J3.8, U4.22 (IO14)
SPI_MISO: J3.2, U4.21 (IO13)
SPI_MOSI: J3.6, U4.19 (IO11)
SPI_SCK: J3.4, U4.20 (IO12)
UART_RX: J1.2, U4.36 (RXD0)
UART_TX: J1.3, U4.37 (TXD0)
USB_D+: J4.A6 (DP1), J4.B6 (DP2), U4.14 (IO20)
USB_D-: J4.A7 (DN1), J4.B7 (DN2), U4.13 (IO19)
VDD: C6.1, J4.A4_B9 (VBUS), J4.B4_A9 (VBUS), PS1.1 (VIN), VUSB.1

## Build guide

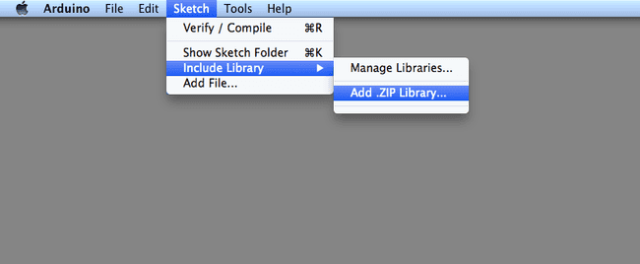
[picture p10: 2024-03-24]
assets/images/arduino-install-ziplibrary.png

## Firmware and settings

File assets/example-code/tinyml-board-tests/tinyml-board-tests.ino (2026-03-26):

#include <Wire.h>
#include <SPI.h>
#include <VL53L0X.h>
#include <SparkFunBME280.h>
#include "SparkFun_BMI270_Arduino_Library.h"
#include <FastLED.h>
// #include <driver/i2s.h>

#define pin_button1 0
#define pin_analog1 1
#define pin_analog2 2
#define pin_analog3 3
#define pin_analog4 4
#define pin_i2s_sd 5
#define pin_i2s_ws 6
#define pin_i2s_sck 7
#define pin_i2c_sda 8
#define pin_i2c_scl 9
#define pin_hall_eff 10
#define pin_spi_mosi 11
#define pin_spi_sck 12
#define pin_spi_miso 13
#define pin_spi_cs 14
#define pin_led 17
#define pin_neopixel 18
#define pin_imu_wake 21
#define pin_button2 47

BME280 envSensor;
VL53L0X vl53Sensor;
BMI270 imuSensor;
#define NUM_LEDS 5
CRGB leds[NUM_LEDS];

// #define SAMPLE_BUFFER_SIZE 512
// #define SAMPLE_RATE 8000
// #define I2S_MIC_CHANNEL I2S_CHANNEL_FMT_ONLY_LEFT
// i2s_config_t i2s_config = {
//   .mode = (i2s_mode_t)(I2S_MODE_MASTER | I2S_MODE_RX),
//   .sample_rate = SAMPLE_RATE,
//   .bits_per_sample = I2S_BITS_PER_SAMPLE_32BIT,
//   .channel_format = I2S_CHANNEL_FMT_ONLY_LEFT,
//   .communication_format = I2S_COMM_FORMAT_I2S,
//   .intr_alloc_flags = ESP_INTR_FLAG_LEVEL1,
//   .dma_buf_count = 4,
//   .dma_buf_len = 1024,
//   .use_apll = false,
//   .tx_desc_auto_clear = false,
//   .fixed_mclk = 0
// };
// i2s_pin_config_t i2s_mic_pins = {
//   .bck_io_num = pin_i2s_sck,
//   .ws_io_num = pin_i2s_ws,
//   .data_out_num = I2S_PIN_NO_CHANGE,
//   .data_in_num = pin_i2s_sd
// };

void setup() {
  Serial.begin(115200);
  while (!Serial)
    ;
  Wire.begin();

  delay(500);
  Serial.println();
  Serial.println();
  Serial.println("############################");
  Serial.println("#  TinyML Board v2.1 test  #");
  Serial.println("#                          #");
  Serial.println("#                          #");
  Serial.println("#  Test all sensors and    #");
  Serial.println("#  functions of the        #");
  Serial.println("#  TinyML Board v2.1       #");
  Serial.println("#                          #");
  Serial.println("#  All instructions        #");
  Serial.println("#  will be preceded by     #");
  Serial.println("#  '***'.                  #");
  Serial.println("############################");
  Serial.println();
  delay(1500);
  Serial.println("*** To Start, press ENTER");
  while (Serial.read() != '\n')
    ;

  // ---------- I2C test ----------
  // Serial.println("I2C Test");
  // Serial.println("Devices expected at 0x29, 0x69 and 0x76");
  // Wire.begin();
  // for (byte address = 1; address < 127; address++) {
  //   Wire.beginTransmission(address);
  //   byte error = Wire.endTransmission();
  //   if (error == 0) {
  //     Serial.print("I2C device found at address 0x");
  //     Serial.print(address, HEX);
  //   } else if (error == 4) {
  //     Serial.print("Unknown error at address 0x");
  //     Serial.println(address, HEX);
  //   }
  // }

  // ---------- BME280 ----------
  Serial.println();
  Serial.println("BME280 Test");

  envSensor.setI2CAddress(0x76);  // Define I2C address
  if (envSensor.beginI2C() == false) {
    Serial.println("Error: Could not find a BME280 sensor!");
    while (1)
      ;
  } else {
    char buffer[100];
    sprintf(buffer, "Temperature: %f °C\nPressure: %f hPa\nHumidity: %f%%", envSensor.readTempC(), envSensor.readFloatPressure() / 100.0F, envSensor.readFloatHumidity());
    Serial.println(buffer);

    Serial.println("*** Check if temperature, pressure and humidity are reasonable values");
    Serial.println("*** To Continue, press ENTER");
    while (Serial.read() != '\n')
      ;
  }

  // ---------- VL53L0X ----------
  Serial.println();
  Serial.println("VL53L0X Test");
  vl53Sensor.setTimeout(500);
  if (!vl53Sensor.init()) {
    Serial.println("Error: Could not find a VL53L0X sensor!");
    while (1)
      ;
  } else {
    vl53Sensor.startContinuous();

    Serial.println("*** Check if different distances are detected");
    Serial.println("*** To Start, press ENTER");
    Serial.println("*** Press ENTER again to quit this test");
    while (Serial.read() != '\n')
      ;
    while (Serial.read() != '\n') {
      delay(100);
      Serial.print(vl53Sensor.readRangeContinuousMillimeters());
      Serial.println(" mm");
    }
  }

  // ---------- BMI270 ----------
  Serial.println();
  Serial.println("BMI270 Test");
  if (imuSensor.beginI2C(0x69) != BMI2_OK) {
    Serial.println("Error: Could not find BMI270!");
    while (1)
      ;
  } else {
    Serial.println("*** Check if movements are detected (these are represented by changes in acceleration (A) and rotation (G))");
    Serial.println("*** To Start, press ENTER");
    Serial.println("*** Press ENTER again to quit this test");
    while (Serial.read() != '\n')
      ;
    while (Serial.read() != '\n') {
      delay(100);
      imuSensor.getSensorData();
      char buffer[150];
      sprintf(buffer, "AccX: %f, AccY: %f, AccZ: %f, GyrX: %f, GyrY: %f, GyrZ: %f", imuSensor.data.accelX, imuSensor.data.accelY, imuSensor.data.accelZ, imuSensor.data.gyroX, imuSensor.data.gyroY, imuSensor.data.gyroZ);
      Serial.println(buffer);
    }
  }

  // ---------- Neopixels ----------
  Serial.println();
  Serial.println("Neopixel Test");
  Serial.println("*** Check if each Neopixel shows colors");
  Serial.println("*** To Start, press ENTER");
  while (Serial.read() != '\n')
    ;
  FastLED.addLeds<NEOPIXEL, pin_neopixel>(leds, NUM_LEDS);
  FastLED.setBrightness(50);
  for (int led = 0; led < NUM_LEDS; led++) {
    leds[led] = CRGB::Red;
    FastLED.show();
    delay(500);
    leds[led] = CRGB::Blue;
    FastLED.show();
    delay(500);
    leds[led] = CRGB::Green;
    FastLED.show();
    delay(500);
    leds[led] = CRGB::White;
    FastLED.show();
    delay(500);
    leds[led] = CRGB::Black;
    FastLED.show();
  }

  // ---------- LED ----------
  Serial.println();
  Serial.println("LED Test");
  Serial.println("*** Check if the on-board LED turns on");
  Serial.println("*** To Start, press ENTER");
  while (Serial.read() != '\n')
    ;
  pinMode(pin_led, OUTPUT);
  for (int leds = 0; leds < 5; leds++) {
    digitalWrite(pin_led, HIGH);
    delay(1000);
    digitalWrite(pin_led, LOW);
    delay(1000);
  }

  // ---------- Buttons ----------
  Serial.println();
  Serial.println("Button Test");
  pinMode(pin_button1, INPUT_PULLUP);
  pinMode(pin_button2, INPUT_PULLUP);
  Serial.println("*** To Continue, Press Button 1");
  bool button_pressed = false;
  while (!button_pressed) {
    if (!digitalRead(pin_button1)) {
      int sum = 0;
      for (int i = 0; i < 8; i++) {
        sum += !digitalRead(pin_button1);
      }
      button_pressed = (sum == 8);
    }
  }
  Serial.println("*** To Continue, Press Button 2");
  button_pressed = false;
  while (!button_pressed) {
    if (!digitalRead(pin_button2)) {
      int sum = 0;
      for (int i = 0; i < 8; i++) {
        sum += !digitalRead(pin_button2);
      }
      button_pressed = (sum == 8);
    }
  }

  // ---------- Hall effect ----------
  Serial.println();
  Serial.println("Hall Effect Test");
  Serial.println("*** Check if changes in voltage by magnet are detected (if no magnet is available, skip this test)");
  Serial.println("*** To Start, press ENTER");
  Serial.println("*** Press ENTER again to quit this test");
  while (Serial.read() != '\n')
    ;
  pinMode(pin_hall_eff, INPUT);
  while (Serial.read() != '\n') {
    delay(100);
    analogRead(pin_hall_eff);
    char buffer[50];
    sprintf(buffer, "%f mV", 3.3 * analogRead(pin_hall_eff) / 4095);
    Serial.println(buffer);
  }

  // ---------- Microphone ----------
  // TODO: fix microphone code with new I2S driver that replaced the legacy I2S driver
  Serial.println("Microphone Test => Currently there is a software bug that prevents the microphone from being tested.");
  // Serial.println();
  // Serial.println("Microphone Test");
  // Serial.println("*** Check if changes output are detected after noise (numbers should be larger both in positive and negative)");
  // Serial.println("*** If you want to check if there are noise-waves, open the Serial Plotter");
  // Serial.println("*** If you whistle there should be a visible sine-wave in the Serial Plotter");
  // Serial.println("*** To Start, press ENTER");
  // Serial.println("*** Press ENTER again to quit this test");
  // while (Serial.read() != '\n')
  //   ;
  // i2s_driver_install(I2S_NUM_0, &i2s_config, 0, NULL);
  // i2s_set_pin(I2S_NUM_0, &i2s_mic_pins);
  // int32_t raw_samples[SAMPLE_BUFFER_SIZE];
  // while (Serial.read() != '\n') {
  //   size_t bytes_read = 0;
  //   i2s_read(I2S_NUM_0, raw_samples, sizeof(int32_t) * SAMPLE_BUFFER_SIZE, &bytes_read, portMAX_DELAY);
  //   int samples_read = bytes_read / sizeof(int32_t);
  //   for (int i = 0; i < samples_read; i++) {
  //     Serial.printf("%ld\n", raw_samples[i]);
  //   }
  // }


  Serial.println();
  Serial.println();
  Serial.println("#######################");
  Serial.println("#  TinyML Board v2.1   #");
  Serial.println("#                      #");
  Serial.println("#  Test finished!      #");
  Serial.println("#  Have fun using the  #");
  Serial.println("#  TinyML Board v2.1!  #");
  Serial.println("########################");
  Serial.println();
  Serial.println();
}

void loop() {}

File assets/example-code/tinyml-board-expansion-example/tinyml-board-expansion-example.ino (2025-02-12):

#define pin_analog1 1
#define pin_analog2 2
#define pin_analog3 3
#define pin_analog4 4

#define pin_spi_mosi 11
#define pin_spi_sck 12
#define pin_spi_miso 13
#define pin_spi_cs 14

int analogOutput = 0;

void setup() {
    Serial.begin(115200);

    pinMode(pin_analog1, INPUT);
    pinMode(pin_analog2, INPUT);

    pinMode(pin_analog3, OUTPUT);
    pinMode(pin_analog4, OUTPUT);

    // The digital pins can also be used as SPI pins, 
    // please refer to specific SPI instructions for their use
    pinMode(pin_spi_mosi, INPUT);
    pinMode(pin_spi_sck, INPUT);
    pinMode(pin_spi_miso, INPUT);
    pinMode(pin_spi_cs, INPUT);
}

void loop() {
    Serial.print("analog1: "); Serial.println(analogRead(pin_analog1));
    Serial.print("analog2: "); Serial.println(analogRead(pin_analog2));

    analogWrite(pin_analog3, analogOutput);
    analogWrite(pin_analog4, 255 - analogOutput);
    
    if (analogOutput < 255) {
        analogOutput++;
    } else {
        analogOutput = 0;
    }

    Serial.print("digital1: "); Serial.println(digitalRead(pin_spi_mosi));
    Serial.print("digital2: "); Serial.println(digitalRead(pin_spi_sck));
    Serial.print("digital3: "); Serial.println(digitalRead(pin_spi_miso));
    Serial.print("digital4: "); Serial.println(digitalRead(pin_spi_cs));

    delay(100);
}

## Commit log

2024-03-24 Add download buttons, installation instruction images
2024-03-24 Added pcb information, updated README with uploading info
    [BOM_PCB_TinyML devkit v2_2024-01-10.csv, TinyML_devboard_v2.1.kicad_pcb]
2024-03-24 fixed typo in pcb README
2024-03-24 Added board test code, updated README to include tests
2024-03-25 Added schematic annotated board images to README
2024-03-26 Fixed button GPIO pin
    [tinyml-board-buttons-example.ino]
2024-03-27 changed default baudrate in imu_example
2024-04-15 Added schematic, updated PCB file
2025-02-12 Updated pcb README, added issues section to README
2025-03-27 Updated Quick Start to include Arduino settings
2026-03-26 Update tinyml-board-tests.ino to relieve microphone test failing
    [tinyml-board-tests.ino]
